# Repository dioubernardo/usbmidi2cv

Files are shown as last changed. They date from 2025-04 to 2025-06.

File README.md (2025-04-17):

# USB MIDI to CV

Project inspired by [elkayem/midi2cv](https://github.com/elkayem/midi2cv), but using MIDI over USB communication.

## Requirements

- Arduino Leonardo or any board based on ATmega32u4 or ARM ([MIDIUSB compatibility](https://docs.arduino.cc/libraries/midiusb/#Compatibility))  
- MCP4728 (PCBs are designed for the generic GY-MCP4728 module)  
- LM324N  
- Some resistors and connectors

> ⚠️ The resistors connected to the A output of the LM324N don't need to match exact values, as long as they maintain an amplification ratio of approximately 1.77. Inaccurate values may affect 1V/Oct tuning.

The operational amplifier is configured as a non-inverting amplifier with the following resistors:

- **R1 = 10kΩ** (between the inverting input and GND)
- **R2 = 6.8kΩ + 900Ω _(from trimpot)_ = 7.7kΩ** (between the output and the inverting input)

The amplification factor (gain) is calculated as:

Amplification = 1 + (R2/R1) = 1 + (7.7kΩ/10kΩ) = 1.77

Therefore, the gain is **1.77x**.

## How It Works

- When a MIDI note is received (regardless of channel), it is converted to CV in 1V/Oct format, with C0 = 0V, C1 = 1V, C2 = 2V... covering 88 notes total.
- When a second note is played, it replaces the previous one, which is kept in a buffer.
- **Velocity** is converted to a voltage ranging from 0V to 4V.
- A **Trigger Pulse** of 5V is sent for 20ms every time a note is triggered.
- The **Gate** stays high (5V) while any note is being played.
- **Pitch Bend** is centered at 0.5V and ranges from 0V to 1V.
- Any **Control Change (CC)** message is converted to a voltage from 0V to 4V.

## Schematic

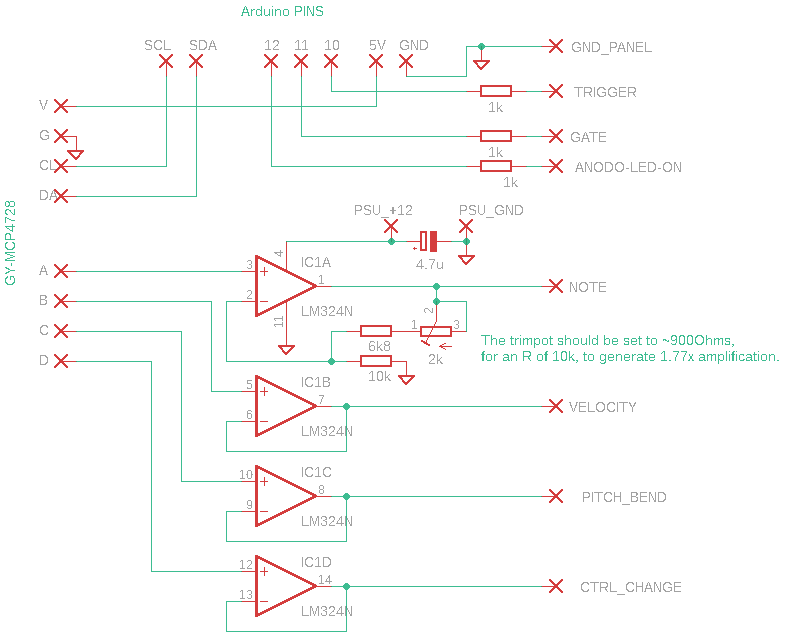
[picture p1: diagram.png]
Schematic


The file [`usbmidi2cv.sch`](https://github.com/dioubernardo/usbmidi2cv/blob/main/usbmidi2cv.sch) contains the schematic and can be edited using Eagle.

## PCB

Designed to work as an Arduino shield, this PCB can be easily etched on a single-sided copper board for DIY builds.

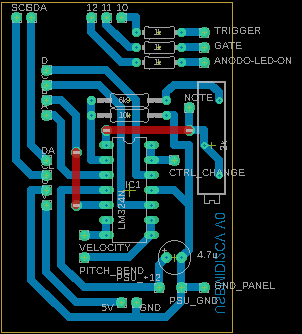
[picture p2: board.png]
Board


The file [`usbmidi2cv.brd`](https://github.com/dioubernardo/usbmidi2cv/blob/main/usbmidi2cv.brd) contains the PCB layout, also editable in Eagle.

To print, use the file [pcb.pdf](https://github.com/dioubernardo/usbmidi2cv/blob/main/pcb.pdf).

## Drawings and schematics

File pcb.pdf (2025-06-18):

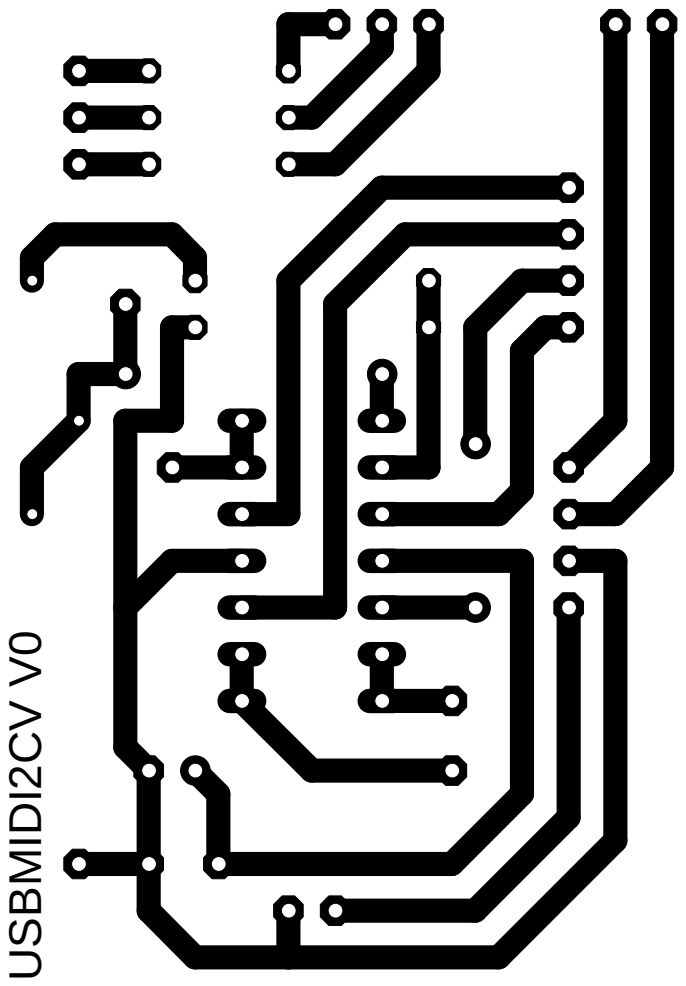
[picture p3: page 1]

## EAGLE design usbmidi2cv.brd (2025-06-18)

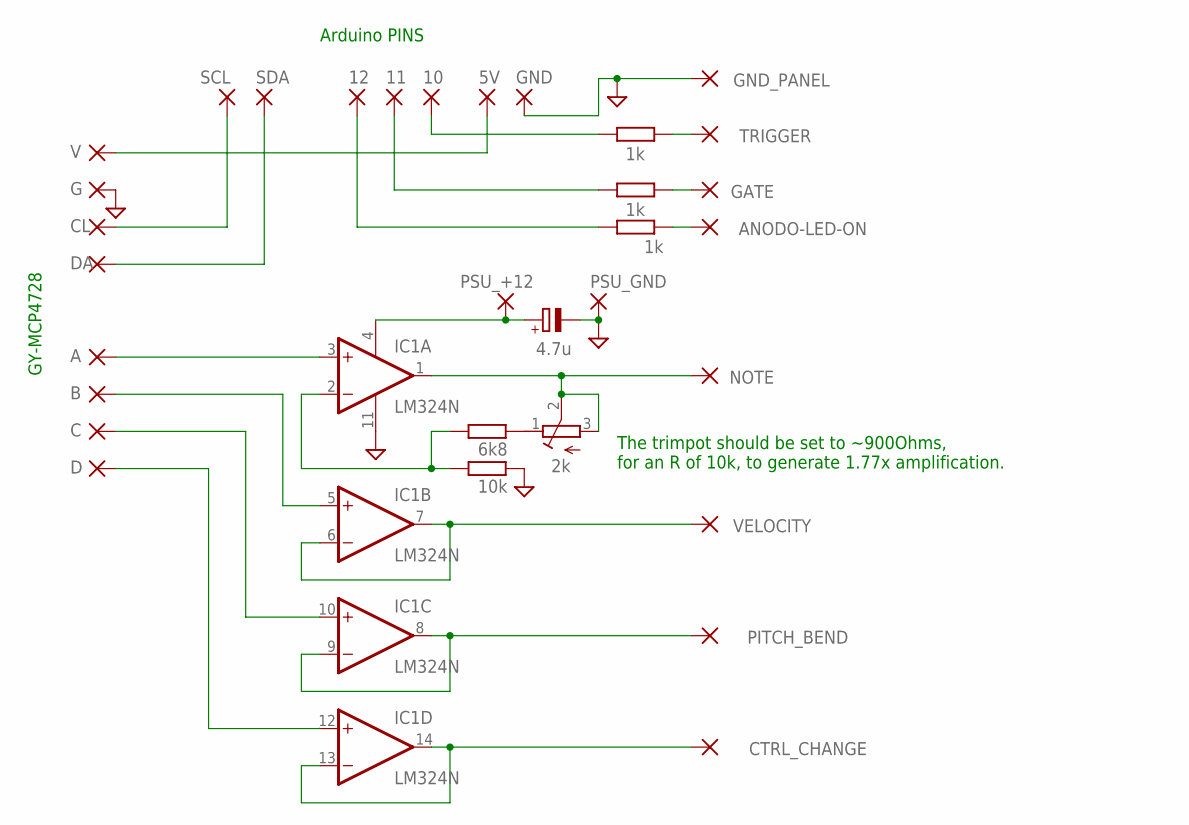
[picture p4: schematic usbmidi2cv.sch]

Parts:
5V, 10, 11, 12: 1,6/0,8
A: 1,6/0,8
ANODO-LED-ON: 1,6/0,8
B: 1,6/0,8
C: 1,6/0,8
C1: 4.7u; E2,5-6
CL: 1,6/0,8
CTRL_CHANGE: 1,6/0,8
D: 1,6/0,8
DA: 1,6/0,8
G: 1,6/0,8
GATE: 1,6/0,8
GND: 1,6/0,8
GND_PANEL: 1,6/0,8
IC1: LM324N; DIL14
NOTE: 1,6/0,8
PITCH_BEND: 1,6/0,8
PSU_+12: 1,6/0,8
PSU_GND: 1,6/0,8
R1, R2, R3: 1k; 0204/7
R4: 10k; 0207/12
R5: 2k; RTRIM3006P
R6: 6k8; 0207/12
SCL: 1,6/0,8
SDA: 1,6/0,8
TRIGGER: 1,6/0,8
V: 1,6/0,8
VELOCITY: 1,6/0,8

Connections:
GND: C1.-, G.1, GND.1, GND_PANEL.1, IC1.11 (V-), PSU_GND.1, R4.2
unnamed: A.1, IC1.3 (+IN)
unnamed: R2.1, TRIGGER.1
unnamed: GATE.1, R1.1
unnamed: 10.1, R2.2
unnamed: 11.1, R1.2
unnamed: ANODO-LED-ON.1, R3.1
unnamed: 12.1, R3.2
unnamed: 5V.1, V.1
unnamed: CL.1, SCL.1
unnamed: DA.1, SDA.1
unnamed: B.1, IC1.5 (+IN)
unnamed: C.1, IC1.10 (+IN)
unnamed: CTRL_CHANGE.1, IC1.13 (-IN), IC1.14 (OUT)
unnamed: IC1.1 (OUT), NOTE.1, R5.2 (S), R5.3 (A)
unnamed: IC1.8 (OUT), IC1.9 (-IN), PITCH_BEND.1
unnamed: IC1.6 (-IN), IC1.7 (OUT), VELOCITY.1
unnamed: IC1.2 (-IN), R4.1, R6.1
unnamed: R5.1 (E), R6.2
unnamed: C1.+, IC1.4 (V+), PSU_+12.1
unnamed: D.1, IC1.12 (+IN)

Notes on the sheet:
Arduino PINS
GY-MCP4728
The trimpot should be set to ~900Ohms, for an R of 10k, to generate 1.77x amplification.

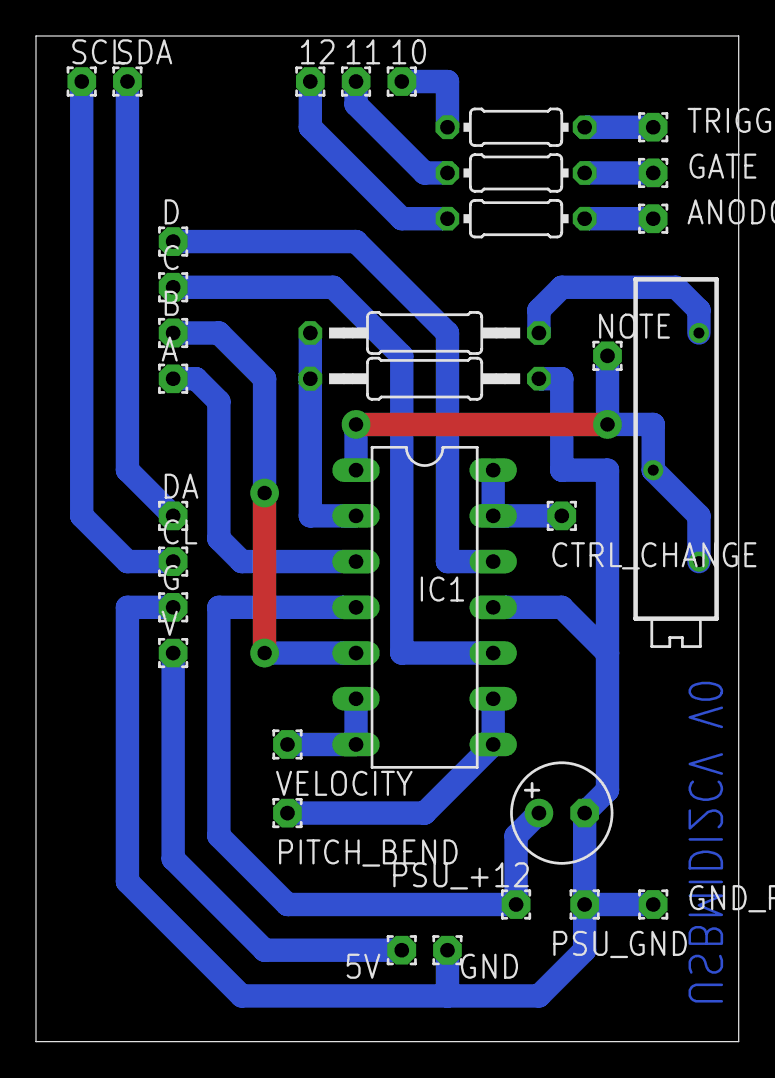
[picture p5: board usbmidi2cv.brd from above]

Board: 2 copper layers, 39.0 x 55.9 mm, 33 parts (0 on the bottom side), 21 nets.

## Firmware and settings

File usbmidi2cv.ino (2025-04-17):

/*
  Monophonic - Last note, with 10 notes in buffer

  Note CV output (88 keys, 1V/octave)                         DAC A
  Velocity CV output (0 to 4V)                                DAC B

  Pitch bend CV output (0 to 1V, witch 0.5 central possition) DAC C
  Control Change CV out (0 to 4V)                             DAC D

  Trigger output (5V, pulso de 20 msec)                       D4
  Gate output (5V quando alguma tecla estiver precionada)     D5
*/

#include "MIDIUSB.h"
#include <Adafruit_MCP4728.h>

#define GATE_PIN    4
#define TRIGGER_PIN 5

const byte bufferSize = 10;
const byte lastIndex = bufferSize - 1;

byte bufferNotes[bufferSize] = {};
byte notes[88] = {};
unsigned long triggerInit = 0;

Adafruit_MCP4728 mcp;

void setup() {
  pinMode(LED_BUILTIN, OUTPUT);

  pinMode(GATE_PIN, OUTPUT);
  digitalWrite(GATE_PIN, LOW);

  pinMode(TRIGGER_PIN, OUTPUT);
  digitalWrite(TRIGGER_PIN, LOW);

  Serial.begin(115200);
  delay(200);

  for (int i = 0; i <= lastIndex; i++) {
    bufferNotes[i] = 255;
  }

  if (!mcp.begin()) {
    Serial.println("Failed to find MCP4728 chip");
    bool on = 0;
    while (1) {
      on = !on;
      digitalWrite(LED_BUILTIN, on ? HIGH : LOW);
      delay(500);
    }
  }

  Serial.println("OK");

  mcp.setChannelValue(MCP4728_CHANNEL_A, 0);
  mcp.setChannelValue(MCP4728_CHANNEL_B, 0);

  // Set initial pitch bend voltage to 0.5V (mid point)
  mcp.setChannelValue(MCP4728_CHANNEL_C, 1023, MCP4728_VREF_INTERNAL, MCP4728_GAIN_1X);

  mcp.setChannelValue(MCP4728_CHANNEL_D, 0);

  digitalWrite(LED_BUILTIN, HIGH);
}

void loop() {

  byte note;
  midiEventPacket_t rx;
  do {
    rx = MidiUSB.read();
    if (rx.header != 0) {
      switch (rx.header) {

        case 0x09: // Note ON

          if (rx.byte2 < 12 || rx.byte2 > 99) // only 88 keys from C0
            break;

          note = rx.byte2 - 12;
          for (int i = (lastIndex - 1); i >= -1; i--) {
            if (bufferNotes[i] != 255 || i == -1) {
              notes[note] = rx.byte3;
              bufferNotes[i + 1] = note;
              emitNote(note);
              break;
            }
          }

          break;

        case 0x08: // Note OFF

          if (rx.byte2 < 12 || rx.byte2 > 99) // only 88 keys, From C0 to D7#
            break;

          note = rx.byte2 - 12;

          int i;
          for (i = lastIndex; i >= 0; i--) {
            if (bufferNotes[i] == note) {
              bufferNotes[i] = 255;
              break;
            }
          }

          for (i = lastIndex; i >= 0; i--) {
            if (bufferNotes[i] != 255) {
              emitNote(bufferNotes[i]);
              break;
            }
          }

          if (i == -1) {
            digitalWrite(GATE_PIN, LOW);
          }

          break;

        case 0x0E: // Pitch Bend

          // Pitch Bend range from 0 to 16383
          // Right shift by 3 to scale from 0 to 2047
          unsigned int val = (rx.byte3 << 7) | rx.byte2;
          mcp.setChannelValue(MCP4728_CHANNEL_C, val >> 3, MCP4728_VREF_INTERNAL, MCP4728_GAIN_1X);

          break;

        case 0x0B: // Control Change
          // CC range from 0 to 127
          // Left shift d2 by 5 to scale from 0 to 4095
          mcp.setChannelValue(MCP4728_CHANNEL_D, rx.byte2 << 5, MCP4728_VREF_INTERNAL, MCP4728_GAIN_2X);

          break;

      }
      /*
            Serial.print(rx.header, HEX);
            Serial.print(" ");
            Serial.print(rx.byte1, HEX);
            Serial.print(" ");
            Serial.print(rx.byte2, HEX);
            Serial.print(" ");
            Serial.print(rx.byte3, HEX);
            Serial.println(" ");
      */

    }
  } while (rx.header != 0);

  if (triggerInit > 0 && (millis() - triggerInit) > 20) {
    triggerInit = 0;
    digitalWrite(TRIGGER_PIN, LOW);
  }
}

void emitNote(byte note) {

  /*
    0 -> 0V
    4095 -> VREF_INTERNAL MCP4728_GAIN_2X -> 4,096V
    Volts per note = 4095 / (88 - 1) = 47.06896551724138
    The OPAMP need amplifier 1,77x
  */
  mcp.setChannelValue(MCP4728_CHANNEL_A, note * 47.06896551724138f, MCP4728_VREF_INTERNAL, MCP4728_GAIN_2X);

  // Velocity range from 0 to 4095 mV
  // Left shift by 5 to scale from 0 to 4095
  mcp.setChannelValue(MCP4728_CHANNEL_B, notes[note] << 5, MCP4728_VREF_INTERNAL, MCP4728_GAIN_2X);

  digitalWrite(GATE_PIN, HIGH);
  digitalWrite(TRIGGER_PIN, HIGH);
  triggerInit = millis();
}

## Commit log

2025-04-17 correção de elemento perdido
    [usbmidi2cv.brd]
2025-05-22 melhorias na pcb
    [usbmidi2cv.brd, usbmidi2cv.sch]
2025-06-18 change soldpad size
    [usbmidi2cv.brd, usbmidi2cv.sch]
